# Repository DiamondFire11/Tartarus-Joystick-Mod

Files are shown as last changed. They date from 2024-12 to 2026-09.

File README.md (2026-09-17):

# Tartarus Analog Joystick Mod | SAMD21 Custom Controller PCB








An electro-mechanical replacement PCB for Razer Tartarus V2/Pro keypads, replacing digital directional pads with an analog joystick module. Features a custom 4-layer stackup, hardware signal conditioning, non-blocking C++ state machines, and integrated power regulation.

---

## 📸 PCB CAD Render
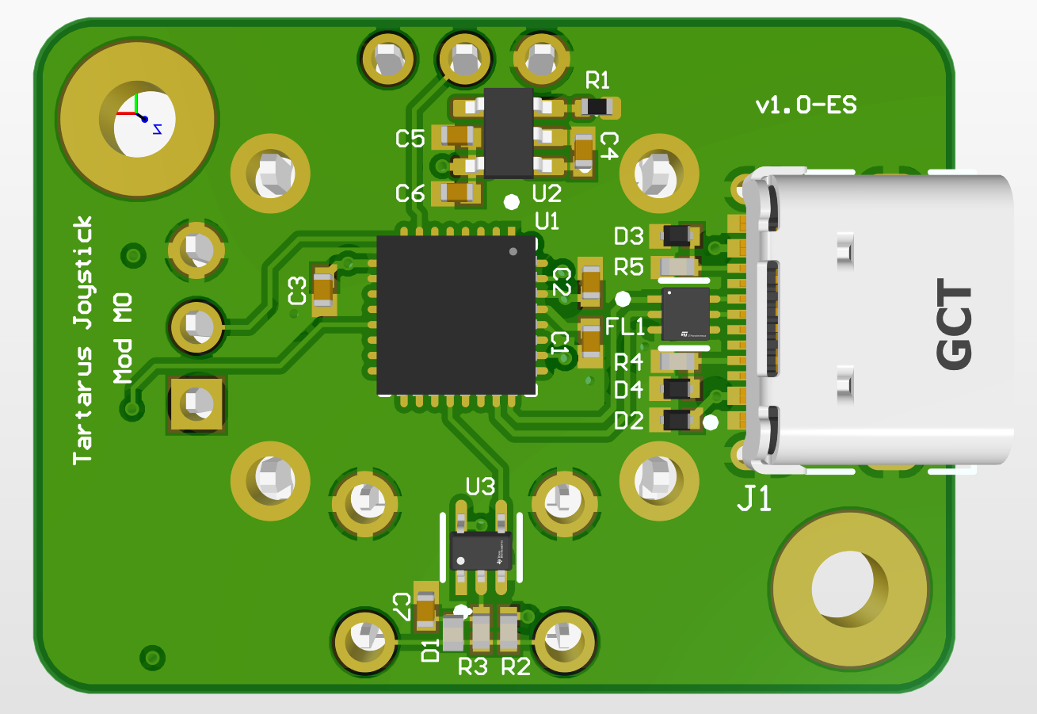
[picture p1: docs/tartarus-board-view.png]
PCB Render


## 🛠 Engineering Highlights & System Architecture

* **4-Layer Controlled Stackup:** Designed in Altium Designer utilizing a compact 22mm x 30mm board footprint. Stackup topology: `Top (Signal/Parts)` $\rightarrow$ `GND Plane (Solid Reference)` $\rightarrow$ `Power Plane (3.3V LDO)` $\rightarrow$ `Bottom (Signal/Traces)` to control return path loop inductance, improve thermal dissipation, and reduce EMI.
* **Hardware-Level Signal Conditioning:** Integrates a two-stage inverting hardware Schmitt-trigger debouncing circuit paired with a fast-acting Schottky diode pull-down network. Bypasses the resistor on discharge to provide near-zero press latency while maintaining a deterministic ~10 ms RC debouncing filter on switch release.
* **32-Bit Microcontroller Architecture:** Powered by an ATSAMD21E18 32-bit ARM Cortex-M0+ MCU. Utilizes non-CPU-blocking polling, efficient bit-wise masking, and custom C++ modular firmware running on PlatformIO for low-latency execution.
* **Signal & Power Integrity:** Native USB 2.0 Type-C interface with dedicated ESD suppression chokes, controlled impedance differential pair routing, onboard LDO regulation, and top-layer component placement.
---

## 📐 System Technical Specifications

| Parameter | Specification Details |
| :--- |:---|
| **Board Dimensions** | 22mm x 30mm (Fits native Razer keypad cavity)|
| **Microcontroller** | Microchip/Atmel SAMD21E18 (32-bit ARM Cortex-M0+, 48MHz)|
| **PCB Stackup** | 4-Layer FR-4 (1.6mm thickness, 1oz Cu outer, solid inner planes)|
| **Hardware Debounce** | Asymmetric ~10 ms release delay (Schmitt Trigger + Schottky diode)|
| **Bus Protocols** | USB 2.0 HID Native, SWD Programming Interface, UART Debugging|
| **Toolchain** | Altium Designer, C++17, PlatformIO / GCC ARM, Atmel-ICE|
---

## 💻 Firmware Architecture & Flashing

The C++ firmware uses modular drivers to maintain low execution time and consistent USB polling rates:

```bash
# Clone repository with PlatformIO configuration
git clone https://github.com/DiamondFire11/Tartarus-Joystick-Mod.git
cd Tartarus-Joystick-Mod

# Build firmware target for SAMD21E18
pio run -e samd21e18_tartarus
```
---

## ⚡ Flashing via SWD & Hardware Debugging
1. Connect an Atmel-ICE or SWD-compatible programmer to the target SWD header pads.
2. Flash the board configuration using PlatformIO or Atmel Studio.
3. **Recovery Mode**: If USB SERCOM arbitration triggers a bus fault during firmware execution, double-tap the physical reset pad to force hardware bootloader mode.
--- 

## 🚀 Roadmap & Design Revisions
* [ ] **EEPROM / Flash Emulation**: Non-volatile storage of analog joystick deadband and runtime calibration offsets across power cycles.
* [ ] **Joy-Con ZIF Interface**: Next board iteration replacing the analog pot with a 0.5mm pitch ZIF flex-connector for Nintendo Switch Joy-Con stick modules.
---

## 📄 License & Hardware Manufacturing Files
* **Production Files**: Production Gerber (.gbr), N.C. Drill (.drl), Solder Paste Stencils (.gtp/.gbp), and Altium Draftsman assembly drawings are located in the /hardware directory
* **License**: Distributed under [GPLv3 License](https://github.com/DiamondFire11/Tartarus-Joystick-Mod/blob/main/LICENSE).

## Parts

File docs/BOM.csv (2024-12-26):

Line # | Name | Description | Designator | Revision ID | Revision State | Revision Status | Quantity | Manufacturer 1 | Manufacturer Part Number 1 | Manufacturer Lifecycle 1 | Supplier 1 | Supplier Part Number 1 | Supplier Unit Price 1 | Supplier Subtotal 1
 | GRM155Z71A105KE01D | Ceramic Capacitor, Multilayer, Ceramic, 10V, 10% +Tol, 10% -Tol, X7R, 15% TC, 1uF, Surface Mount, 0402 | C1, C4, C5, C7 | CMP-001-00092-1 | Draft | Up to date | 4 | Murata | GRM155Z71A105KE01D | Volume Production | Digikey | 490-GRM155Z71A105KE01DCT-ND | 0.022 | 0.22
 | 04025C104KAT4A | Ceramic Capacitor, Multilayer, Ceramic, 50V, 10% +Tol, 10% -Tol, X7R, 15% TC, 0.1uF, Surface Mount, 0402 | C2, C3 | CMP-001-00090-1 | Draft | Up to date | 2 | Kyocera AVX | 04025C104KAT4A | Unknown | Mouser | 581-04025C104KAT4A | 0.1 | 0.2
 | GRM155R61A106ME11J | Ceramic Capacitor, Multilayer, Ceramic, 10V, 20% +Tol, 20% -Tol, X5R, 15% TC, 10uF, Surface Mount, 0402 | C6 | CMP-001-00091-1 | Draft | Up to date | 1 | Murata | GRM155R61A106ME11J | Volume Production | Mouser | 81-GRM155R61A106ME1J | 0.11 | 0.11
 | LTST-C190GKT | LED Uni-Color Green, 100 mW, 30 mA, -55 to 85 degC, 2-Pin SMD, RoHS, Tape and Reel | DS1, DS2, DS3 | CMP-007-00022-2 | Draft | Up to date | 3 | Vishay Lite-On | LTST-C190GKT | Volume Production | Future Electronics | 3106685 | 0.176 | 0.528
 | USB4105-GF-A | Conn USB 2.0 Type C RCP 24 POS 0.3mm/0.5mm Solder RA SMD 24 Terminal 1 Port T/R | J1 | CMP-002-00095-3 | Draft | Out of date | 1 | Global Connector Technology | USB4105-GF-A | Volume Production | Mouser | 640-USB4105-GF-A | 0.84 | 0.84
 | GRPB052VWVN-RC | Connector Header Through Hole 10 position 0.050 (1.27mm) | J2 | CMP-002-00094-2 | Draft | Up to date | 1
 | 100KR2F | 100K 0.063W 1% 0402 (1005 Metric) SMD | R1 | CMP-009-00064-2 | Draft | Up to date | 1
 | MCS04020C5101FE000 | Fixed Resistor, Thin Film, 0.063W, 5100ohm, 50V, 1% +/-Tol, 50ppm/Cel, Surface Mount, 0402 | R2, R4, R5 | CMP-009-00205-1 | Draft | Up to date | 3 | Vishay BCcomponents | MCS04020C5101FE000 | Volume Production | Mouser | 594-MCS04020C5101FE0 | 0.1 | 0.3
 | MCS04020C2202FE000 | Fixed Resistor, Thin Film, 0.063W, 22000ohm, 50V, 1% +/-Tol, 50ppm/Cel, Surface Mount, 0402 | R3 | CMP-009-00206-1 | Draft | Up to date | 1 | Vishay BCcomponents | MCS04020C2202FE000 | Volume Production | Mouser | 594-MCS04020C2202FE0 | 0.1 | 0.1
 | ERJ-2RKF1430X | Fixed Resistor, Metal Glaze/thick Film, 0.1W, 143ohm, 50V, 1% +/-Tol, 100ppm/Cel, Surface Mount, 0402 | R6 | CMP-009-00208-1 | Draft | Up to date | 1 | Panasonic | ERJ-2RKF1430X | Volume Production | Farnell | 2302542 | 0.01505 | 0.15052
 | CRCW040259R0FKED | Fixed Resistor, Metal Glaze/thick Film, 0.063W, 59ohm, 50V, 1% +/-Tol, 100ppm/Cel, Surface Mount, 0402 | R7, R8 | CMP-009-00207-1 | Draft | Up to date | 2 | Vishay | CRCW040259R0FKED | Volume Production | Mouser | 71-CRCW0402-59-E3 | 0.017 | 0.17
 | TL3365AF180QG | Tactile Switch SPST-NO Top Actuated Surface Mount | SW1 | CMP-011-00019-2 | Draft | Up to date | 1
 | ATSAMD21E18A-MU | RISC Microcontroller, 32-Bit, FLASH, CORTEX-M0 CPU, 48MHz, CMOS | U1 | CMP-020-00023-1 | Draft | Up to date | 1 | Microchip | ATSAMD21E18A-MU | Volume Production | Mouser | 556-ATSAMD21E18A-MU | 3.87 | 3.87
 | NCP718BSN330T1G | Fixed Positive LDO Regulator, 3.3V, 440V Dropout, PDSO5 | U2 | CMP-019-00058-1 | Draft | Up to date | 1 | ON Semiconductor | NCP718BSN330T1G | Volume Production | Arrow Electronics | NCP718BSN330T1G | 0.6312 | 0.6312
 | SN74AUP1T14DCKR | Inverter, AUP/ULP/V Series, 1-Func, 1-Input, CMOS, PDSO5 | U3 | CMP-016-00010-1 | Draft | Up to date | 1 | Texas Instruments | SN74AUP1T14DCKR | Volume Production | Digikey | 296-27392-1-ND | 0.24 | 0.24
 | THB001P | Joystick, 2 - Axis Analog (Resistive) Output | U4 | CMP-062-000000-2 | Draft | Up to date | 1
 | CDBQR54 | Rectifier Diode, Schottky, 1 Phase, 1 Element, 0.2A, 30V V(RRM), Silicon | D1 | CMP-004-00041-1 | Draft | Up to date | 1 | Comchip | CDBQR54-HF | Volume Production | Arrow Electronics | CDBQR54-HF | 0.0024 | 0.0024
 | CPDQ5V0 | 18.6V Clamp 9.4A (8/20Âµs) Ipp Tvs Diode Surface Mount 0402/SOD-923F | D2, D3, D4 | CMP-004-00042-2 | Draft | Up to date | 3
 | ECMF02-2AMX6 | Data Line Filter, 2 Function(s), 6 Pin(s), Plastic | FL1 | CMP-00030-00005-1 | Draft | Up to date | 1 | STMicroelectronics | ECMF02-2AMX6 | Volume Production | Newark | 98Y2152 | 0.277 | 0.277

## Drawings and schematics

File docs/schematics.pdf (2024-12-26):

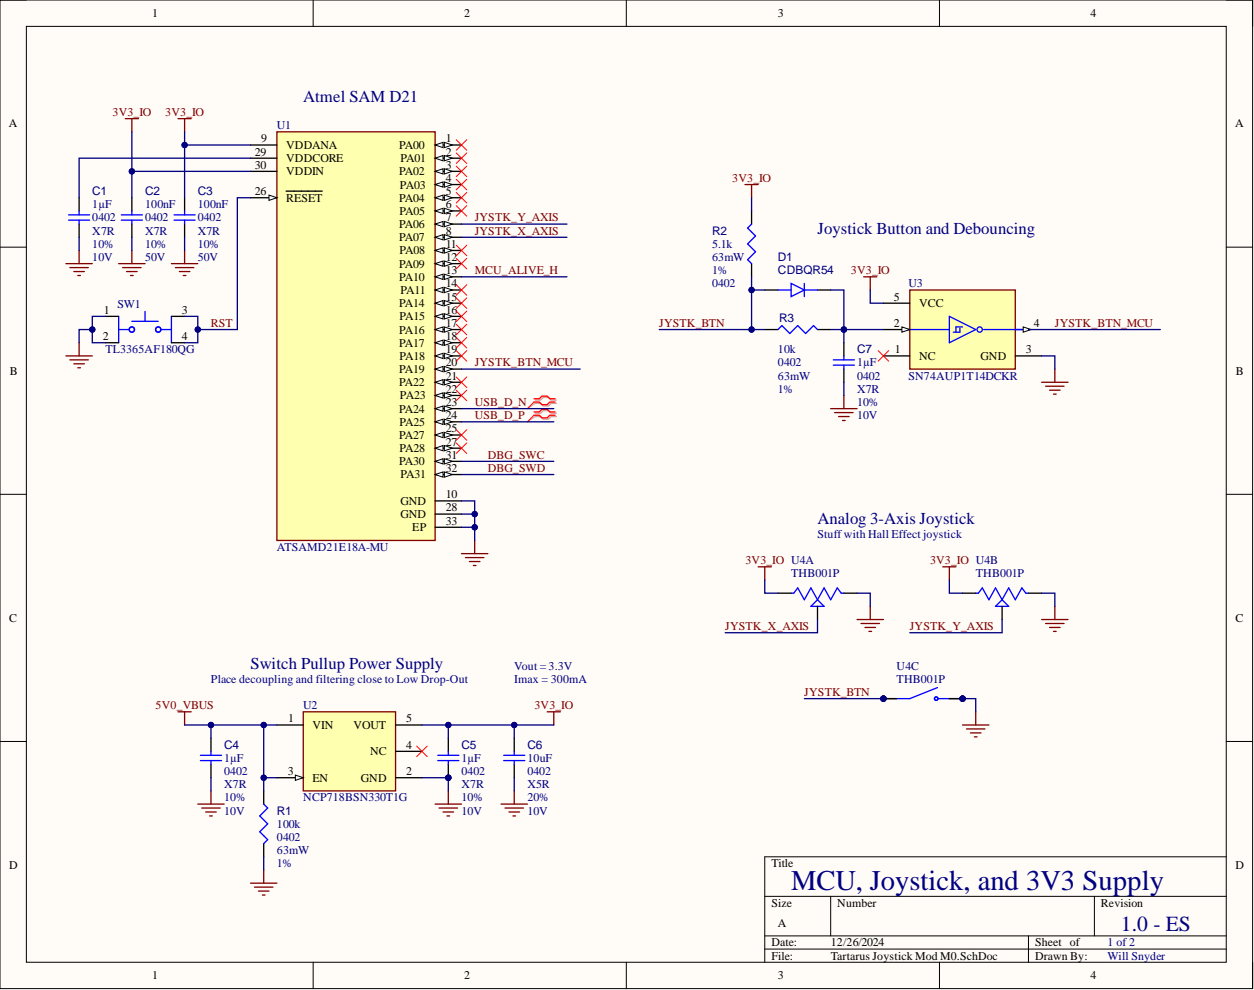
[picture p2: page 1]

VDDCORE 29

C1 | VDDIN 30

100nF 0402 X7R 10% 50V RST

Joystick Button and Debouncing

Analog 3-Axis Joystick
Stuff with Hall Effect joystick

Place decoupling and filtering close to Low Drop-Out

Title
MCU, Joystick, and 3V3 Supply

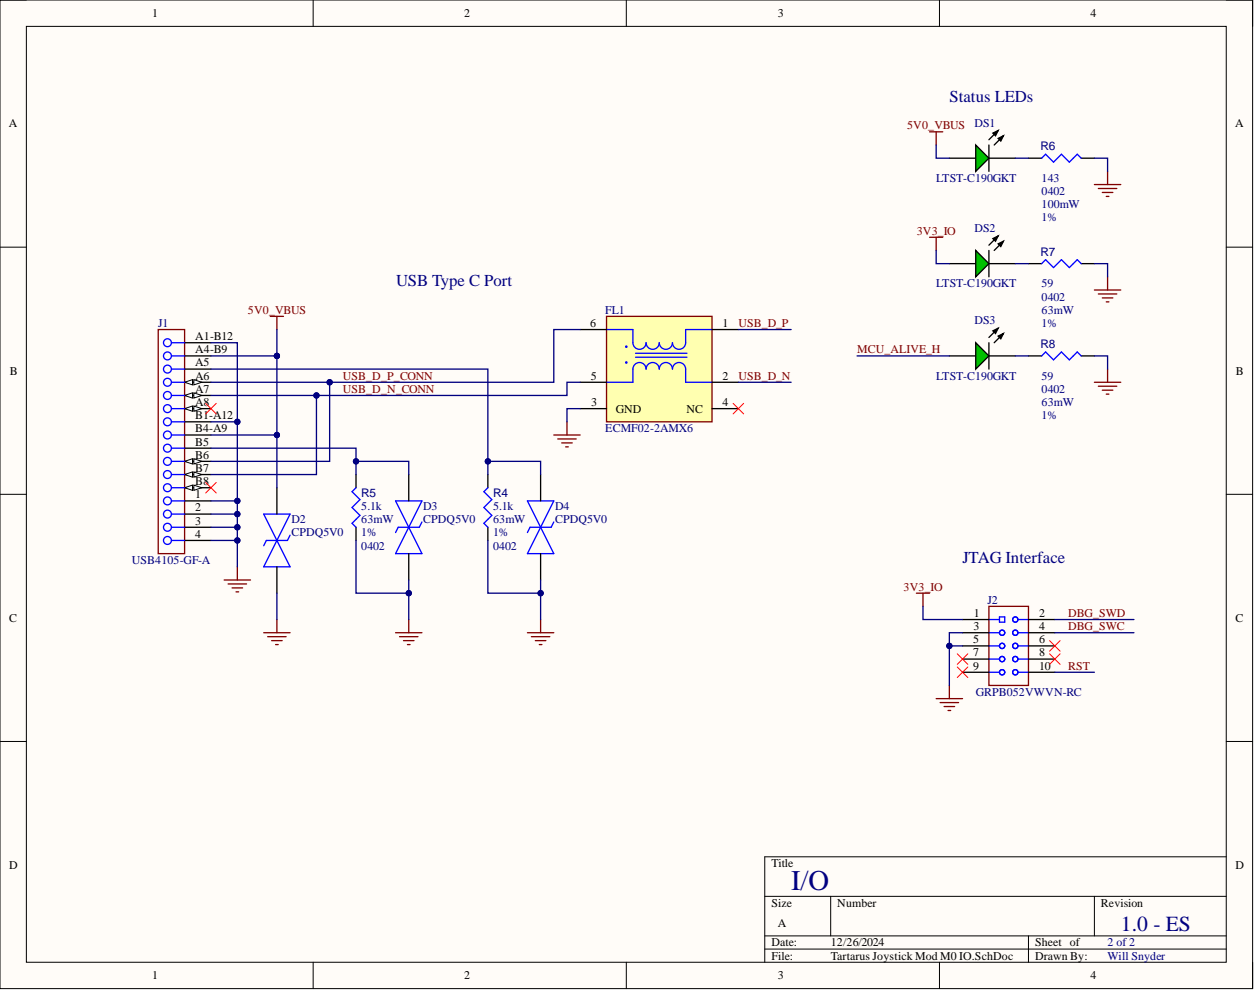
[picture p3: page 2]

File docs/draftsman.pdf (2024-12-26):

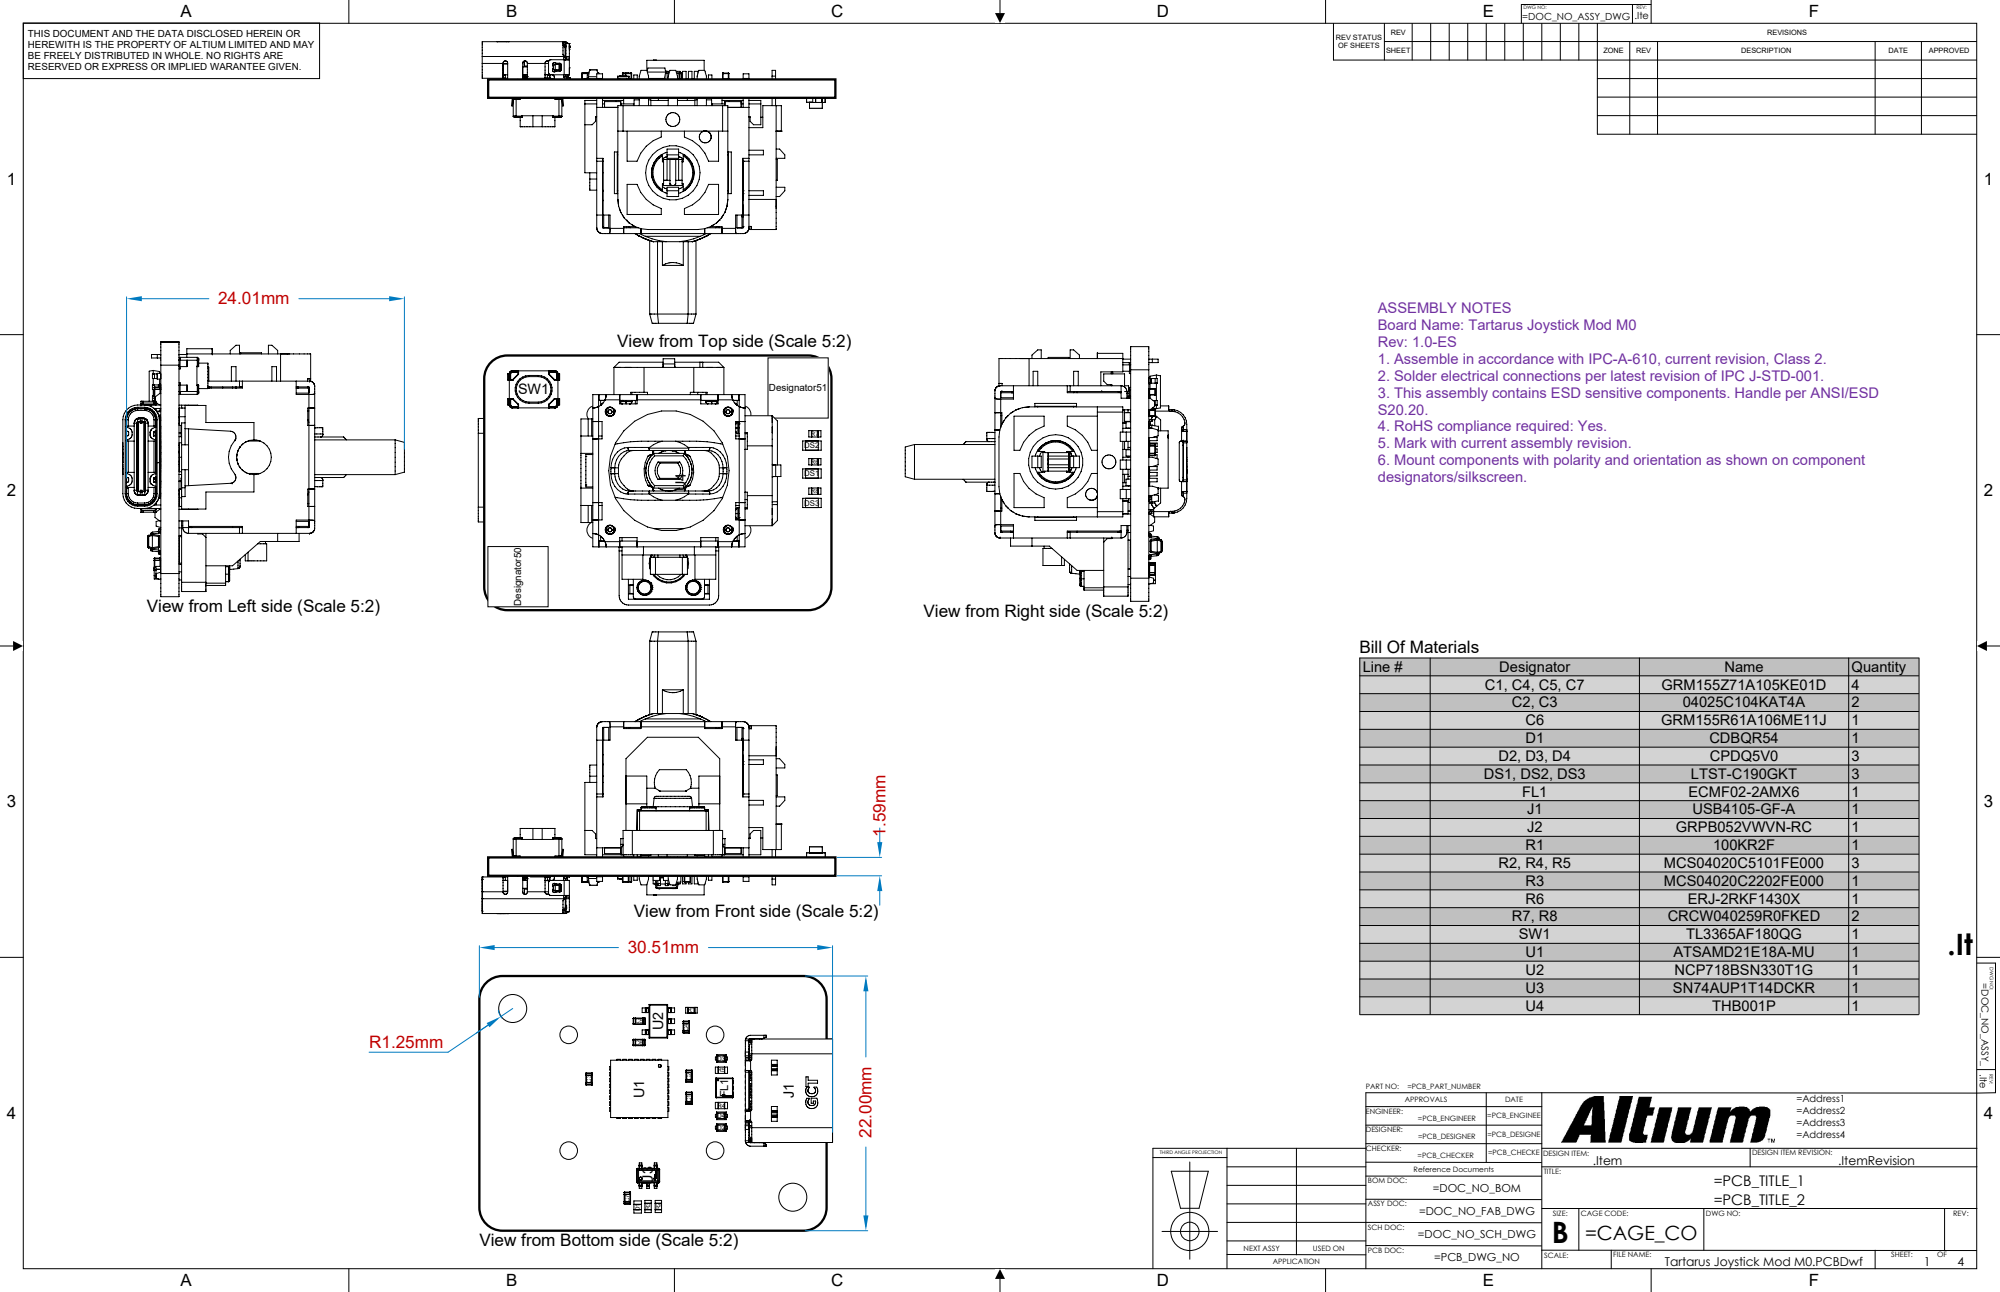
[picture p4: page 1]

View from Top side (Scale 5:2) J1

HEREWITH IS THE PROPERTY OF ALTIUM LIMITED AND MAY
BE FREELY DISTRIBUTED IN WHOLE. NO RIGHTS ARE
RESERVED OR EXPRESS OR IMPLIED WARANTEE GIVEN.

ASSEMBLY NOTES
Board Name: Tartarus Joystick Mod M0
Rev: 1.0-ES
1. Assemble in accordance with IPC-A-610, current revision, Class 2.
2. Solder electrical connections per latest revision of IPC J-STD-001.
3. This assembly contains ESD sensitive components. Handle per ANSI/ESD
4. RoHS compliance required: Yes.
5. Mark with current assembly revision.
6. Mount components with polarity and orientation as shown on component
designators/silkscreen.

Line # | Designator | Name | Quantity

C1, C4, C5, C7 | GRM155Z71A105KE01D | 4
C2, C3 | 04025C104KAT4A | 2
C6 | GRM155R61A106ME11J | 1
D1 | CDBQR54 | 1
D2, D3, D4 | CPDQ5V0 | 3
DS1, DS2, DS3 | LTST-C190GKT | 3
FL1 | ECMF02-2AMX6 | 1
J1 | USB4105-GF-A | 1
J2 | GRPB052VWVN-RC | 1
R1 | 100KR2F | 1
R2, R4, R5 | MCS04020C5101FE000 | 3
R3 | MCS04020C2202FE000 | 1
R6 | ERJ-2RKF1430X | 1
R7, R8 | CRCW040259R0FKED | 2
SW1 | TL3365AF180QG | 1
U1 | ATSAMD21E18A-MU | 1
U2 | NCP718BSN330T1G | 1
U3 | SN74AUP1T14DCKR | 1
U4 | THB001P | 1

View from Front side (Scale 5:2)

APPROVALS | DATE

ENGINEER: =PCB_ENGINEER | =PCB_ENGINEE

DESIGNER: =PCB_DESIGNER | =PCB_DESIGNE

THIRD ANGLE PROJECTION

CHECKER: =PCB_CHECKER | =PCB_CHECKE

View from Bottom side (Scale 5:2)

SCH DOC: =DOC_NO_SCH_DWG

NEXT ASSY | USED ON

Tartarus Joystick Mod M0.PCBDwf

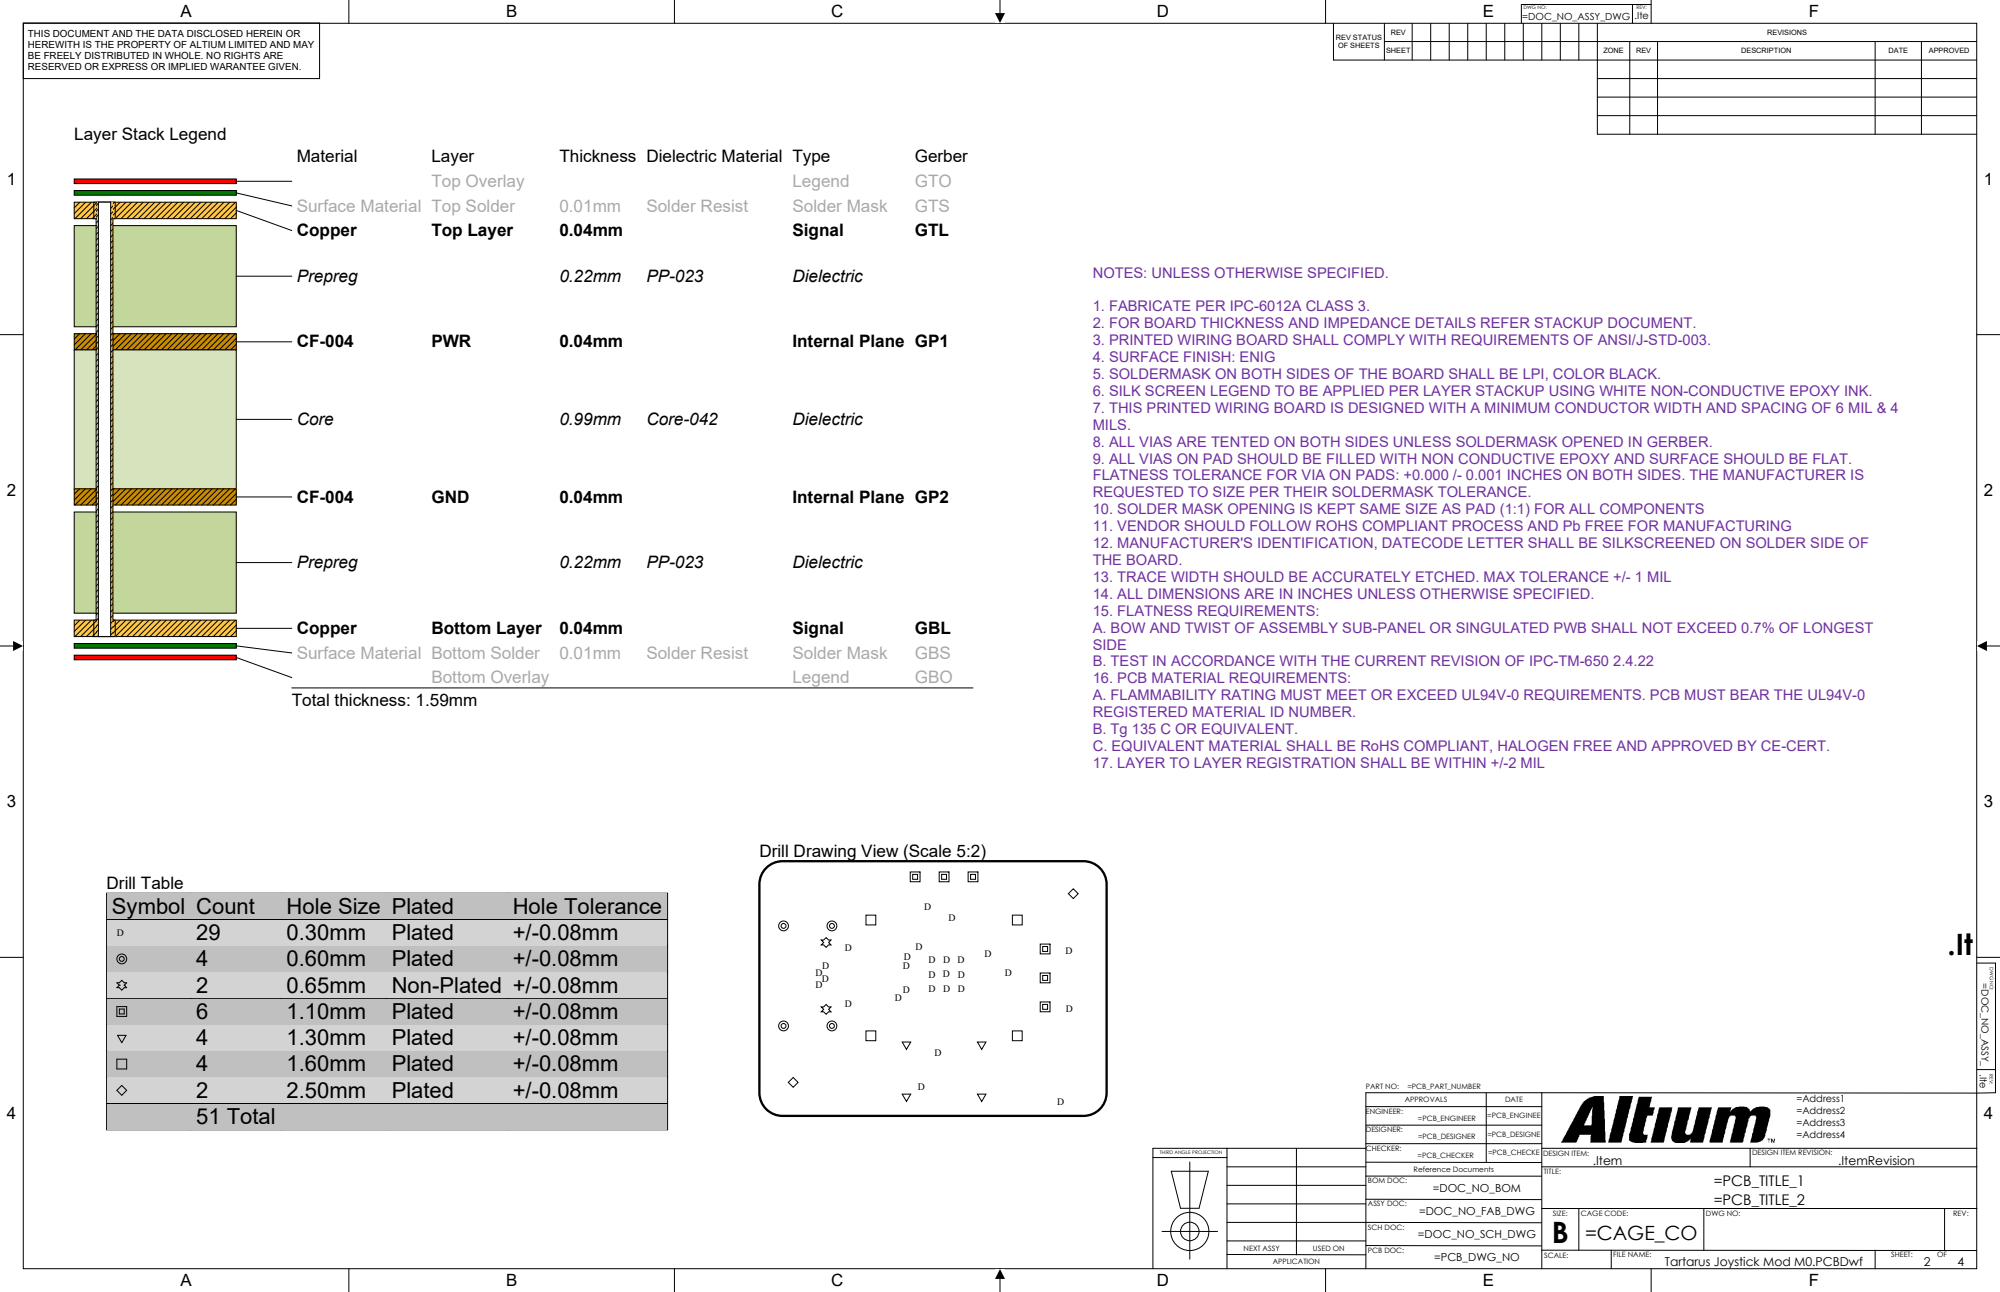
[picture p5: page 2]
Reference Documents; DWG NO:; DESIGN ITEM:; DESIGN ITEM REVISION:; PART NO: =PCB_PART_NUMBER; Material; Layer; Thickness Dielectric Material Type; Gerber; Top Overlay; Legend; GTO; Surface Material Top Solder; Solder Resist; Solder Mask; GTS; Copper; Top Layer; Signal; GTL; PWR; Internal Plane GP1; GND; Internal Plane GP2; Bottom Layer 0.04mm; GBL; Surface Material Bottom Solder 0.01mm; GBS; Bottom Overlay; GBO; Total thickness: 1.59mm; 51 Total; Drill Table

Layer Stack Legend

NOTES: UNLESS OTHERWISE SPECIFIED.

1. FABRICATE PER IPC-6012A CLASS 3.
2. FOR BOARD THICKNESS AND IMPEDANCE DETAILS REFER STACKUP DOCUMENT.
3. PRINTED WIRING BOARD SHALL COMPLY WITH REQUIREMENTS OF ANSI/J-STD-003.
4. SURFACE FINISH: ENIG
5. SOLDERMASK ON BOTH SIDES OF THE BOARD SHALL BE LPI, COLOR BLACK.
6. SILK SCREEN LEGEND TO BE APPLIED PER LAYER STACKUP USING WHITE NON-CONDUCTIVE EPOXY INK.
7. THIS PRINTED WIRING BOARD IS DESIGNED WITH A MINIMUM CONDUCTOR WIDTH AND SPACING OF 6 MIL & 4
MILS.
8. ALL VIAS ARE TENTED ON BOTH SIDES UNLESS SOLDERMASK OPENED IN GERBER.
9. ALL VIAS ON PAD SHOULD BE FILLED WITH NON CONDUCTIVE EPOXY AND SURFACE SHOULD BE FLAT.
FLATNESS TOLERANCE FOR VIA ON PADS: +0.000 /- 0.001 INCHES ON BOTH SIDES. THE MANUFACTURER IS
REQUESTED TO SIZE PER THEIR SOLDERMASK TOLERANCE.
10. SOLDER MASK OPENING IS KEPT SAME SIZE AS PAD (1:1) FOR ALL COMPONENTS
11. VENDOR SHOULD FOLLOW ROHS COMPLIANT PROCESS AND Pb FREE FOR MANUFACTURING
12. MANUFACTURER'S IDENTIFICATION, DATECODE LETTER SHALL BE SILKSCREENED ON SOLDER SIDE OF
THE BOARD.
13. TRACE WIDTH SHOULD BE ACCURATELY ETCHED. MAX TOLERANCE +/- 1 MIL
14. ALL DIMENSIONS ARE IN INCHES UNLESS OTHERWISE SPECIFIED.
15. FLATNESS REQUIREMENTS:
A. BOW AND TWIST OF ASSEMBLY SUB-PANEL OR SINGULATED PWB SHALL NOT EXCEED 0.7% OF LONGEST
SIDE
B. TEST IN ACCORDANCE WITH THE CURRENT REVISION OF IPC-TM-650 2.4.22
16. PCB MATERIAL REQUIREMENTS:
A. FLAMMABILITY RATING MUST MEET OR EXCEED UL94V-0 REQUIREMENTS. PCB MUST BEAR THE UL94V-0
REGISTERED MATERIAL ID NUMBER.
B. Tg 135 C OR EQUIVALENT.
C. EQUIVALENT MATERIAL SHALL BE RoHS COMPLIANT, HALOGEN FREE AND APPROVED BY CE-CERT.
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

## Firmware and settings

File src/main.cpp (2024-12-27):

#include <Arduino.h>

#include "includes/joystickFSM.h"        // Joystick Finite State Machine
#include "includes/ledFSM.h"             // LED Finite State Machine

typedef struct Task {
    int state;
    uint32_t period;
    uint32_t elapsedTime;
    int (*tickFcn) (int);
} Task;

Task tasks[2];

void setup() {
    pinMode(LED_BUILTIN, OUTPUT);
    pinMode(JOYSTICK_BUTTON, INPUT);

    Serial.begin(9600); // Start USB Serial
    Serial.println("Hello from Tartarus Joystick Mod M0 v1.0");

    // LED State-Machine setup
    tasks[0].state = LEDStates::LED_INIT;
    tasks[0].period = 500000;
    tasks[0].elapsedTime = 0;
    tasks[0].tickFcn = &ledTick;

    // Joystick State-Machine setup
    tasks[1].state = JoystickStates::JOYSTICK_INIT;
    tasks[1].period = 500;
    tasks[1].elapsedTime = 0;
    tasks[1].tickFcn = &joystickTick;
}

void loop() {
    for (auto & task : tasks) {
        if ((micros() - task.elapsedTime) >= task.period) {
            task.state = task.tickFcn(task.state);
            task.elapsedTime = micros(); // Last time this task was ran
        }
    }
}

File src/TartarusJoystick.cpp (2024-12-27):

//
// Created by Will Snyder on 12/23/24.
//

#include "includes/TartarusJoystick.h"

TartarusJoystick::TartarusJoystick() {
    // Placeholder calibration settings load, will be read from SAM D21 EEPROM.
    // Consider adding EEPROM to future revision.
    this->m_settings = JoystickSettings{{56, 19},
                                        {1023, 1010},
                                        {571, 526},
                                        51, 51, 1.0};

    // Initialize data variable
    this->m_data = {{0, 0}, false};

    // Initialize keys
    this->m_keys[0] = {NAN, NAN, KEY_BUTTON, false}; // Button is special case
    this->m_keys[1] = {1.17, 5.08, KEY_LEFT, false}; // Left is special case due to singularity
    this->m_keys[2] = {0.39, 2.74, KEY_UP, false};
    this->m_keys[3] = {1.96, 4.30, KEY_RIGHT, false};
    this->m_keys[4] = {3.52, 5.89, KEY_DOWN, false};

    Keyboard.begin(); // Start keyboard for keystroke capability
}

// Tweak with proper smoothing and deadzone adherence
void TartarusJoystick::readJoystickData() {
    // raw pot X and Y reading
    int16_t xVal, yVal;

    // Read pot values
    xVal = (int16_t) analogRead(A4);
    yVal = (int16_t) analogRead(A3);

    // Apply calibration to X and Y values
    xVal = (int16_t) map(xVal, this->m_settings.minPos.x, this->m_settings.maxPos.x,
                         0, 1023);

    yVal = (int16_t) map(yVal, this->m_settings.minPos.y, this->m_settings.maxPos.y,
                         0, 1023);

    this->m_applySmoothing(xVal, yVal);
    this->m_applyDeadzone(xVal, yVal);

    // Map X and Y values to [-100, 100] with deadzones
    xVal = (int16_t) map(xVal, 0, 1023, JOYSTICK_MINIMUM, JOYSTICK_MAXIMUM);
    yVal = (int16_t) map(yVal, 0, 1023, JOYSTICK_MINIMUM, JOYSTICK_MAXIMUM);

    this->m_data.position.x = constrain(xVal, JOYSTICK_MINIMUM, JOYSTICK_MAXIMUM);
    this->m_data.position.y = constrain(yVal, JOYSTICK_MINIMUM, JOYSTICK_MAXIMUM);

    this->m_data.button = digitalRead(JOYSTICK_BUTTON);
}

void TartarusJoystick::printToSerial() const {
    Serial.print("Position (x, y): ");
    this->m_data.position.printToSerial();
    Serial.print(" Button: ");
    Serial.println(this->m_data.button);

    Serial.print("Angle (rad): ");
    Serial.println(atan2(this->m_data.position.y, this->m_data.position.x) + M_PI);
}

// Point printToSerial() implementation
void Point::printToSerial() const {
    Serial.print("(");
    Serial.print(x);
    Serial.print(", ");
    Serial.print(y);
    Serial.print(")");
}

void TartarusJoystick::m_applyDeadzone(int16_t & xVal, int16_t & yVal) const {
    if(abs(xVal - this->m_settings.origin.x) <= this->m_settings.xDeadzone) {
        xVal = 512;
    }

    if(abs(yVal - this->m_settings.origin.y) <= this->m_settings.yDeadzone) {
        yVal = 512;
    }
}

// Scale sensitivity dependent on the distance from the origin
// Range between 0.1 - 2.0.
void TartarusJoystick::m_applySmoothing(int16_t & xVal, int16_t & yVal) const {
    xVal = (int16_t)(this->m_settings.origin.x +
                     (xVal - this->m_settings.origin.x) *
                     this->m_settings.sensitivityScaling);

    yVal = (int16_t)(this->m_settings.origin.y +
                     (yVal - this->m_settings.origin.y) *
                     this->m_settings.sensitivityScaling);
}

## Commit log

2024-12-26 Update README.md
    Added simple readme. Will add PCB pictures later
2024-12-26 Rename BOM_[No Variations].csv to hardware/docs/BOM.csv
    [BOM.csv]
2024-12-26 Rename Schematic PDF_[No Variations]-2.pdf to hardware/docs/Schematics.pdf
2024-12-27 Update main.cpp
    Changed FSM timing with new keystroke algorithm to support 1000Hz refresh
2026-09-16 Revise README for Tartarus Joystick Mod details
    Updated the README to reflect new project title, features, and technical specifications for the Tartarus Analog Joystick Mod. Added badges for version, license, MCU, CAD, framework, language, and int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
2026-09-17 Add board view for README
2026-09-17 Change PCB render image link in README
    Updated PCB render image link in README.md.
2026-09-17 Add files via upload
    Commit PCB design documents for Altium Designer.
    [Tartarus Joystick Mod M0 IO.SchDoc, Tartarus Joystick Mod M0.PcbDoc, Tartarus Joystick Mod M0.PrjPcb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]

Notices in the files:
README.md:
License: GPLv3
